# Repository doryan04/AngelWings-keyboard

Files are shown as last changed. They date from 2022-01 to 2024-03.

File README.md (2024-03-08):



# Angel Wings Keyboard (by [@ItzAdel](https://github.com/doryan04) and [@nm17](https://github.com/nm17))

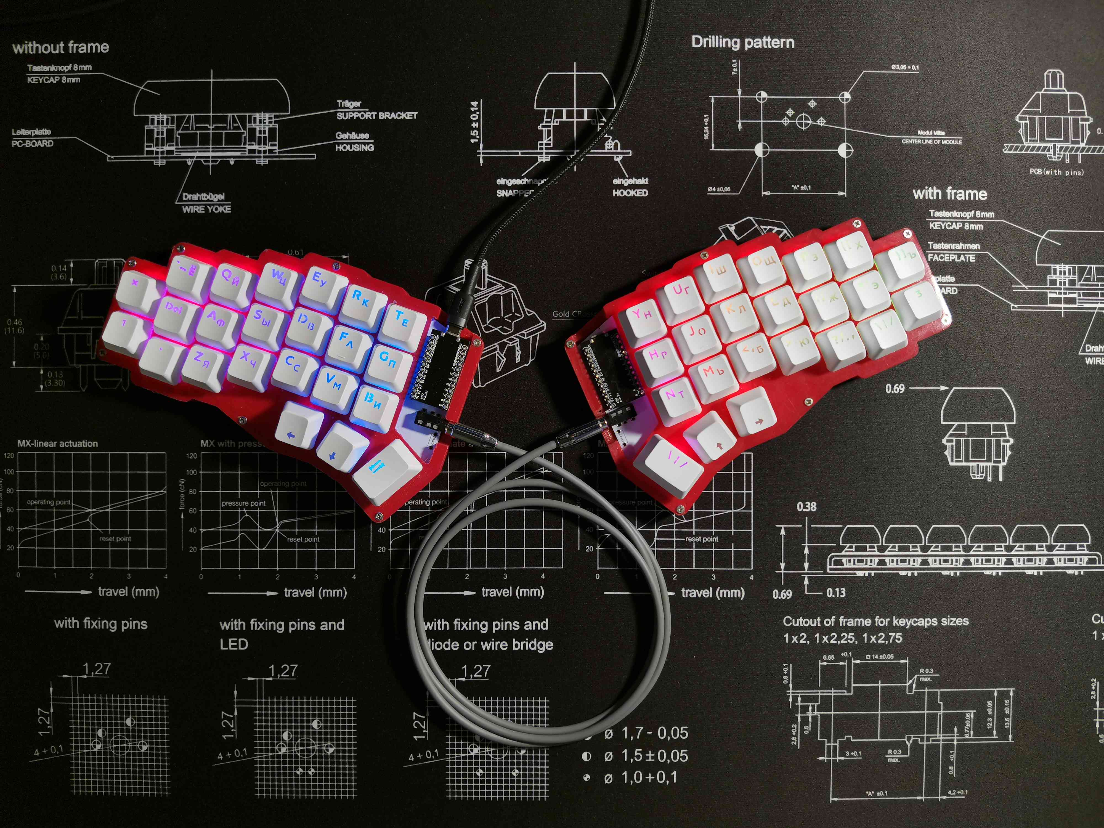
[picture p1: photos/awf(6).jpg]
Main Photo


# Keymap

The Lower, Raise and Adjust layers are provided to allow you to use full-size keys that are not on this keyboard.

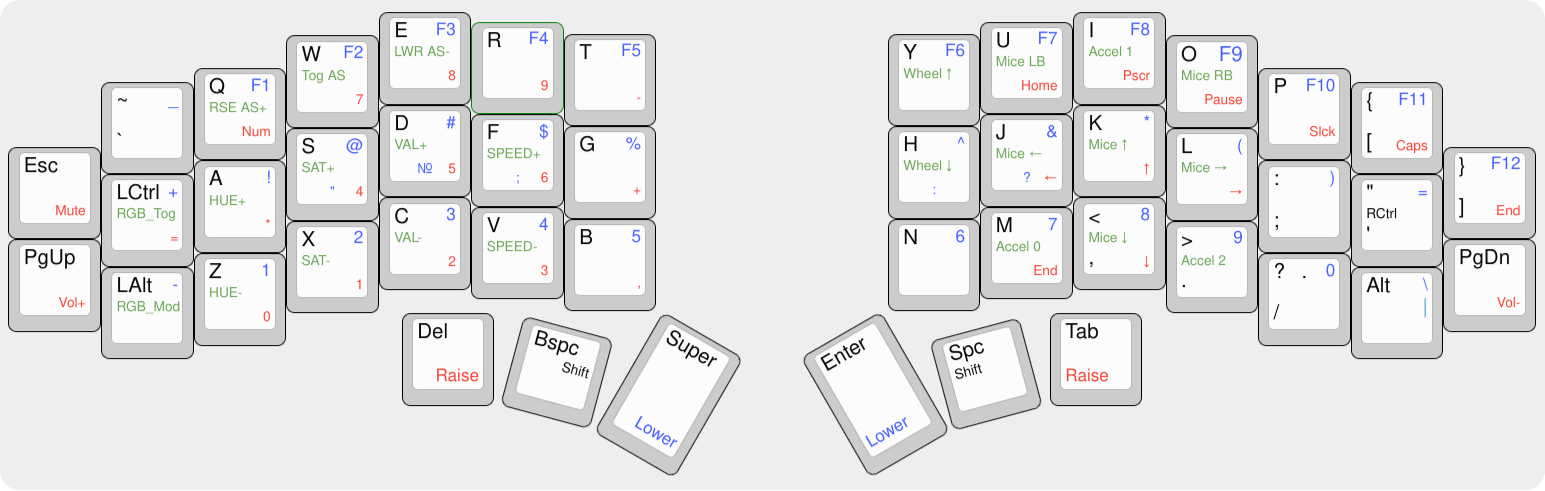
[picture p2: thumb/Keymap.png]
Keymap


To use one or the other layer, you need to press one of the following keys:
- Super/Enter for Lower.
- Tab/Delete for Raise
- To switch to the Adjust layer, press Enter + Tab / Super + Del

### Check [wiki](https://github.com/ItzAdel/AngelWings-keyboard/wiki/INFO) for more info

# Photos

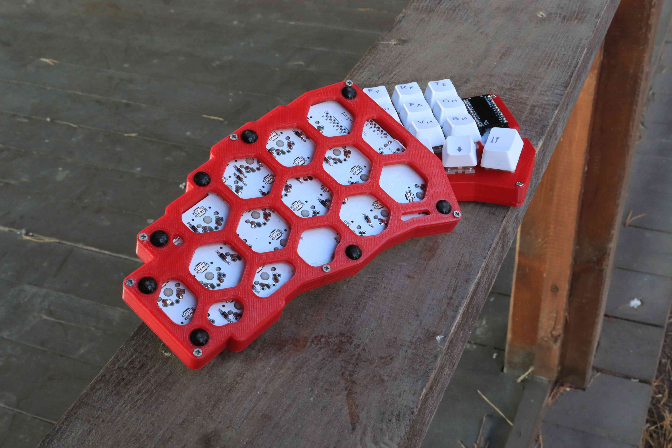
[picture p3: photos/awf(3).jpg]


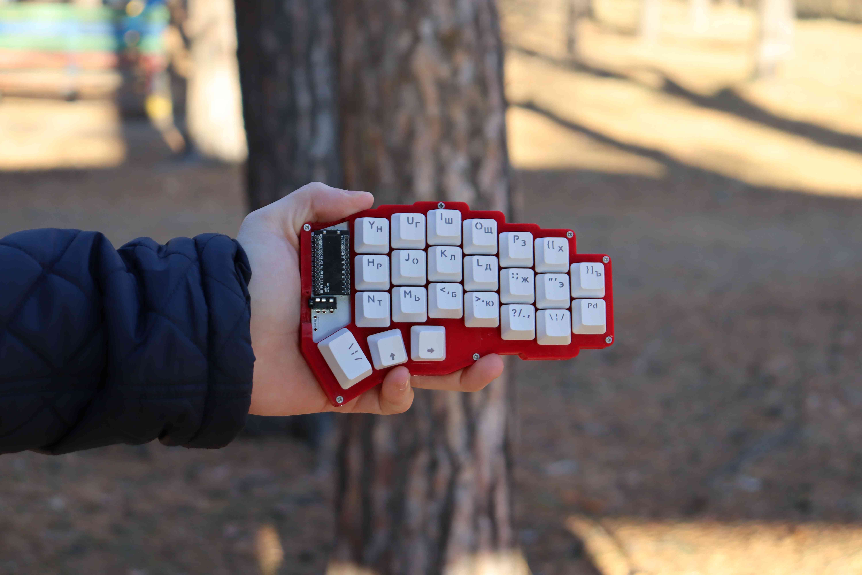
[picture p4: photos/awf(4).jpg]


# Nowadays, this repository is archived
## Check out updates AWF on [my gitea](https://gitea.doryan04.ru/doryan/AWF)

### Check out actual news on Telegram. https://t.me/doryanProjects

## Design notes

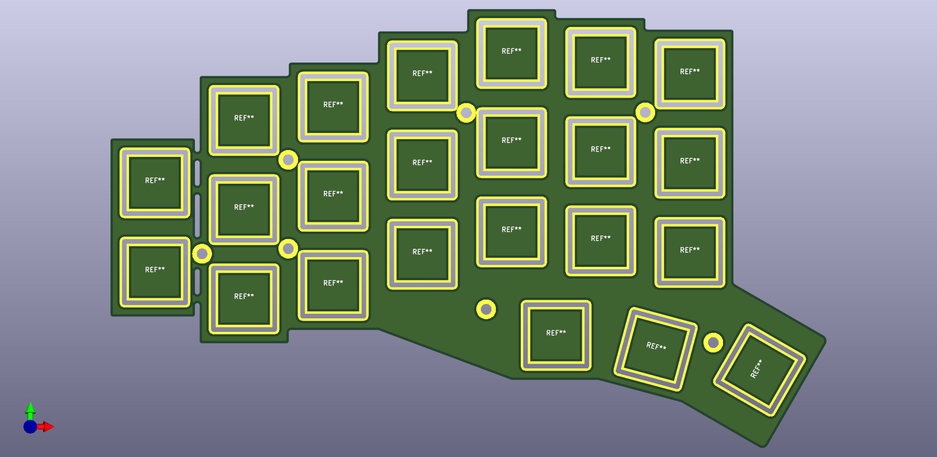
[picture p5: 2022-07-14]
photos/topplate.png

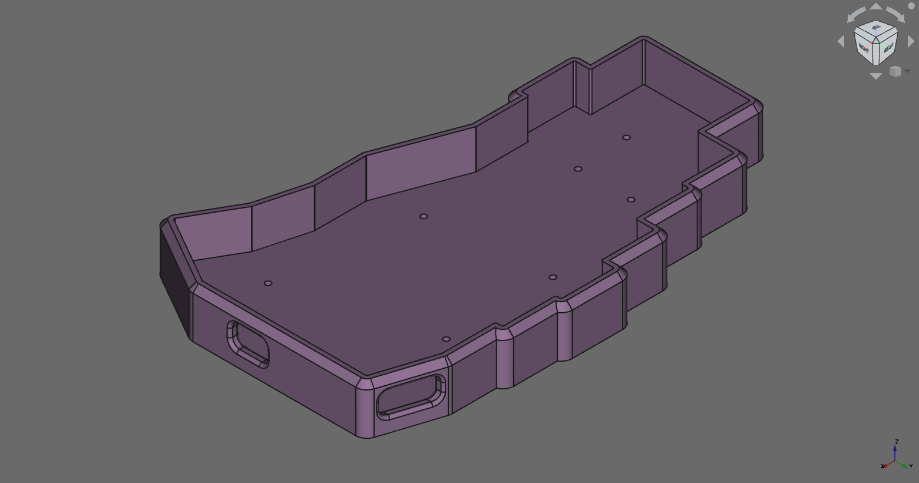
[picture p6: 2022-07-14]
cases/Pic/case3.png

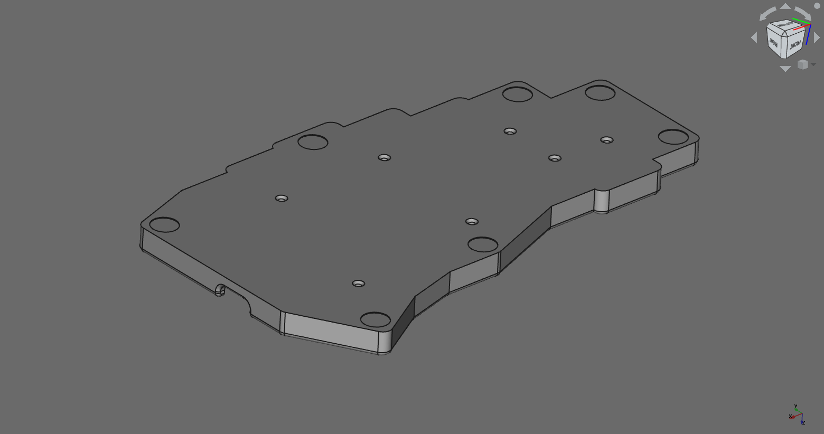
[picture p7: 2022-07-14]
cases/Pic/case1.png

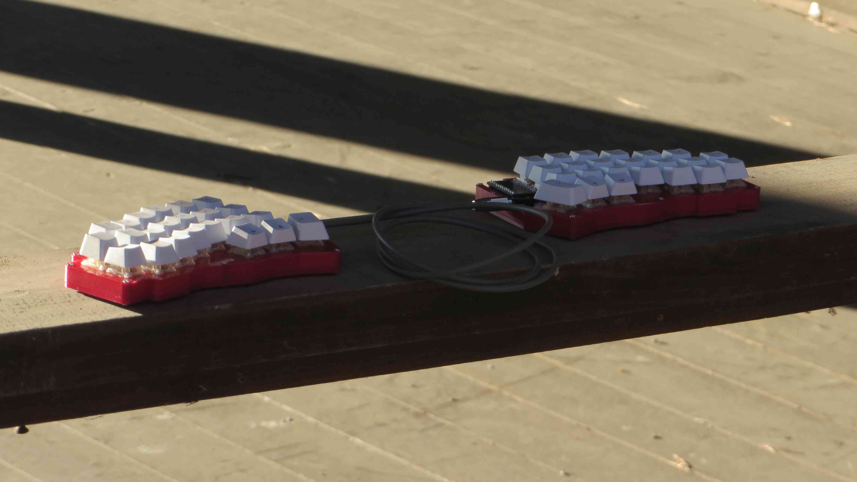
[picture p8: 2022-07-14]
photos/awf(2).jpg

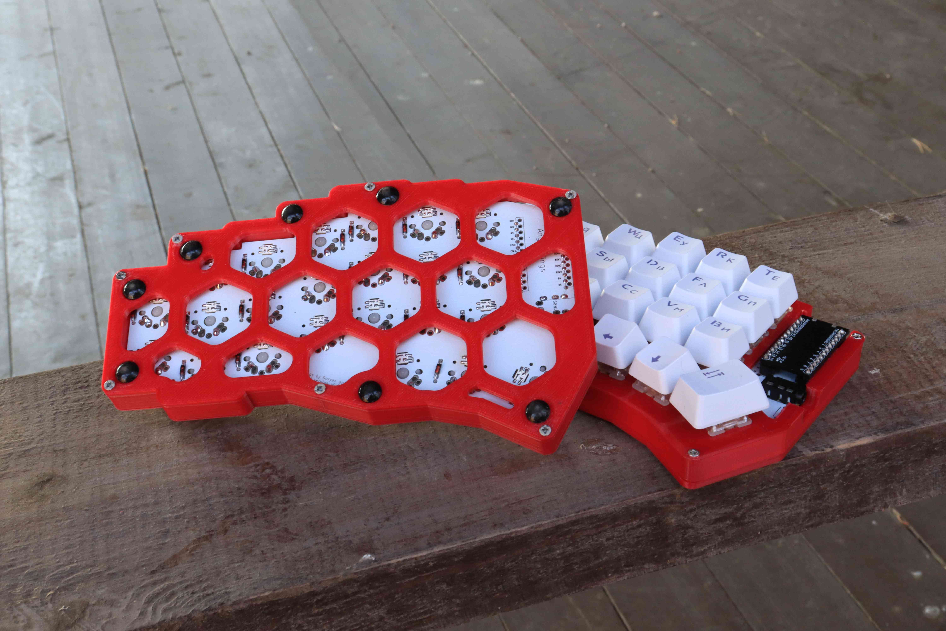
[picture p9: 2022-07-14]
photos/awf(5).jpg

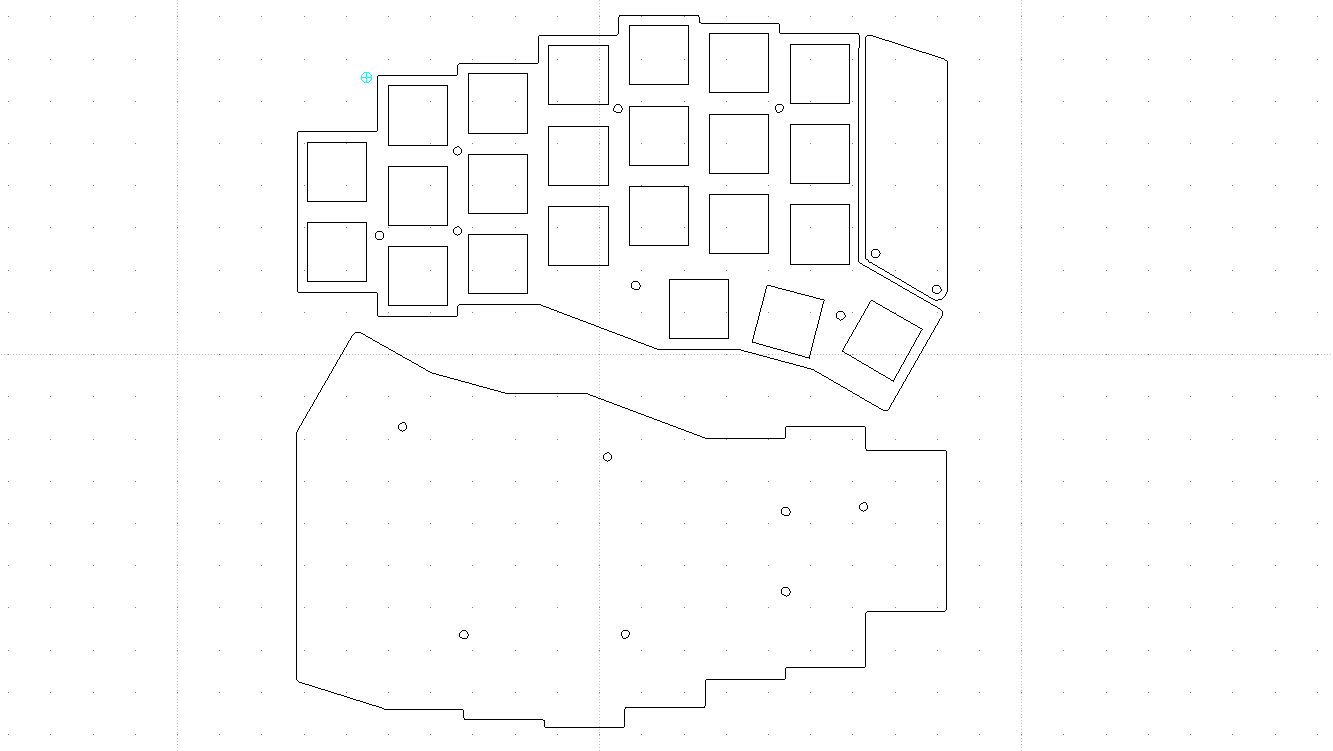
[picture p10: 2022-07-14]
cases/Pic/plates.png

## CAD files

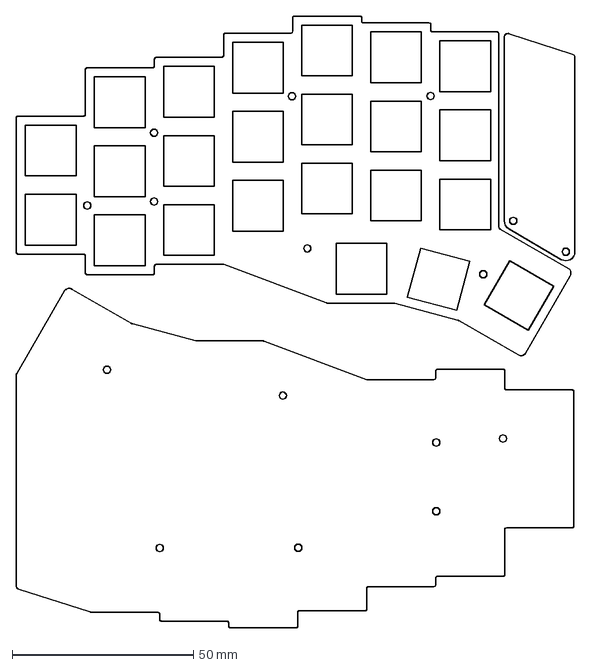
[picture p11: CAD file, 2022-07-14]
cases/Plates/plates.dxf
154.2 x 168.8 mm

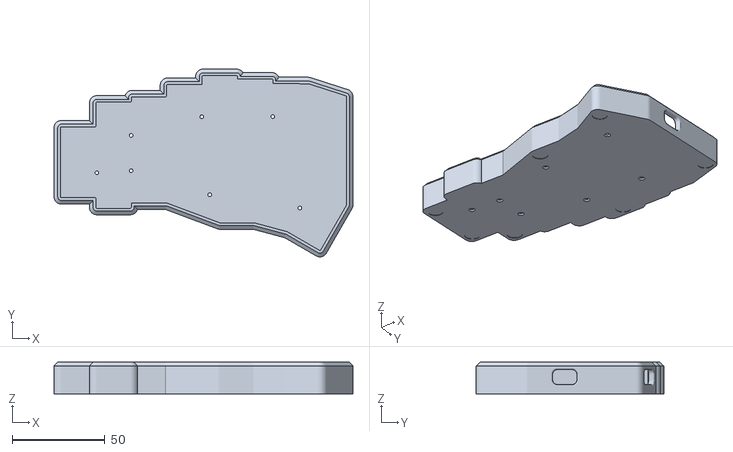
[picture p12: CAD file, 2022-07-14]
cases/STL cases/mxCase.stl
160.9 x 101.0 x 17.0

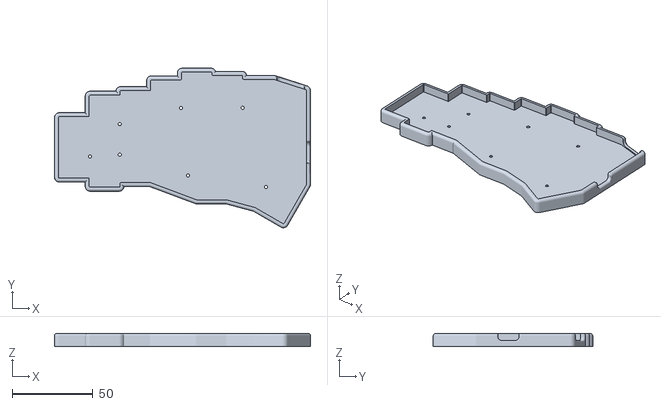
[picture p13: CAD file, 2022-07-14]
cases/STL cases/chocCase.stl
158.9 x 99.0 x 8.20

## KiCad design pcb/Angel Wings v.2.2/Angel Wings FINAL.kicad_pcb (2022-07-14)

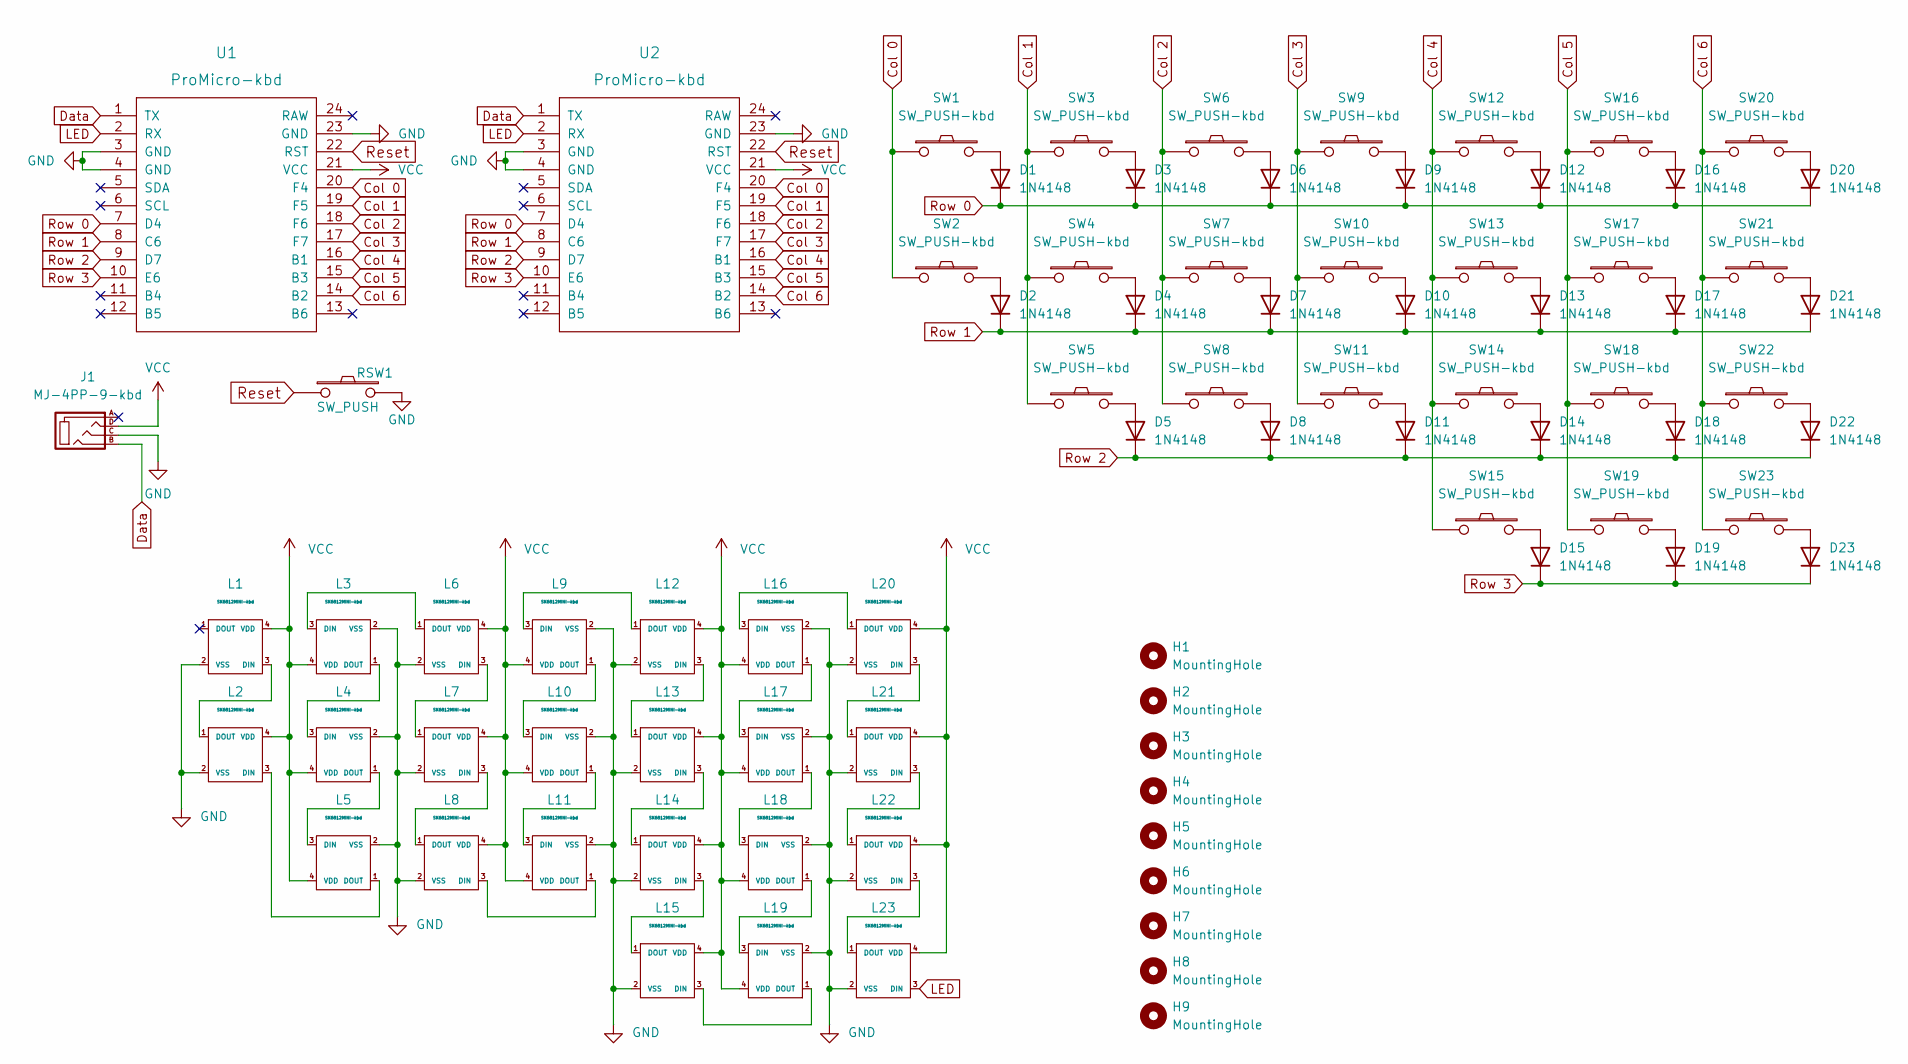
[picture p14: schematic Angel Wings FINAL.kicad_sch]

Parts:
D1, D2, D3, D4, D5, D6, D7, D8, D9, D10, D11, D12, D13, D14, D15, D16, D17, D18, D19, D20, D21, D22, D23: 1N4148; D3_TH_SMD
H1, H2: MountingHole; LEGO_HOLE
H3, H4, H5, H6, H7, H8, H9: MountingHole; M2_Hole_TH_Outside
J1: MJ-4PP-9-kbd; MJ-4PP-9
L1, L2, L3, L4, L5, L6, L7, L8, L9, L10, L11, L12, L13, L14, L15, L16, L17, L18, L19, L20, L21, L22, L23: SK6812MINI-kbd; SK6812MINI_rev
RSW1: SW_PUSH; ResetSW
SW1, SW2, SW3, SW4, SW5, SW6, SW7, SW8, SW9, SW10, SW11, SW12, SW13, SW14, SW15, SW16, SW17, SW18, SW19, SW20, SW21, SW22, SW23: SW_PUSH-kbd; MX_ALPS_PG1350_noLed
U1: ProMicro-kbd; ProMicro_Flipped_v2_A
U2: ProMicro-kbd; ProMicro_Flipped_v2_B

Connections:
Col 0: SW1.1, SW2.1, U1.20 (F4), U2.20 (F4)
Col 1: SW3.1, SW4.1, SW5.1, U1.19 (F5), U2.19 (F5)
Col 2: SW6.1, SW7.1, SW8.1, U1.18 (F6), U2.18 (F6)
Col 3: SW9.1, SW10.1, SW11.1, U1.17 (F7), U2.17 (F7)
Col 4: SW12.1, SW13.1, SW14.1, SW15.1, U1.16 (B1), U2.16 (B1)
Col 5: SW16.1, SW17.1, SW18.1, SW19.1, U1.15 (B3), U2.15 (B3)
Col 6: SW20.1, SW21.1, SW22.1, SW23.1, U1.14 (B2), U2.14 (B2)
Data: J1.B, U1.1 (TX), U2.1 (TX)
GND: J1.C, L1.2 (VSS), L2.2 (VSS), L3.2 (VSS), L4.2 (VSS), L5.2 (VSS), L6.2 (VSS), L7.2 (VSS), L8.2 (VSS), L9.2 (VSS), L10.2 (VSS), L11.2 (VSS), L12.2 (VSS), L13.2 (VSS), L14.2 (VSS), L15.2 (VSS), L16.2 (VSS), L17.2 (VSS), L18.2 (VSS), L19.2 (VSS), L20.2 (VSS), L21.2 (VSS), L22.2 (VSS), L23.2 (VSS), RSW1.2, U1.3 (GND), U1.4 (GND), U1.23 (GND), U2.3 (GND), U2.4 (GND), U2.23 (GND)
LED: L23.3 (DIN), U1.2 (RX), U2.2 (RX)
unnamed: D1.2 (A), SW1.2
unnamed: D2.2 (A), SW2.2
unnamed: D3.2 (A), SW3.2
unnamed: D4.2 (A), SW4.2
unnamed: D5.2 (A), SW5.2
unnamed: D6.2 (A), SW6.2
unnamed: D7.2 (A), SW7.2
unnamed: D8.2 (A), SW8.2
unnamed: D9.2 (A), SW9.2
unnamed: D10.2 (A), SW10.2
unnamed: D11.2 (A), SW11.2
unnamed: D12.2 (A), SW12.2
unnamed: D13.2 (A), SW13.2
unnamed: D14.2 (A), SW14.2
unnamed: D15.2 (A), SW15.2
unnamed: D16.2 (A), SW16.2
unnamed: D17.2 (A), SW17.2
unnamed: D18.2 (A), SW18.2
unnamed: D19.2 (A), SW19.2
unnamed: D20.2 (A), SW20.2
unnamed: D21.2 (A), SW21.2
unnamed: D22.2 (A), SW22.2
unnamed: D23.2 (A), SW23.2
unnamed: L1.3 (DIN), L2.1 (DOUT)
unnamed: L2.3 (DIN), L5.1 (DOUT)
unnamed: L3.1 (DOUT), L4.3 (DIN)
unnamed: L3.3 (DIN), L6.1 (DOUT)
unnamed: L4.1 (DOUT), L5.3 (DIN)
unnamed: L6.3 (DIN), L7.1 (DOUT)
unnamed: L7.3 (DIN), L8.1 (DOUT)
unnamed: L10.1 (DOUT), L11.3 (DIN)
unnamed: L9.1 (DOUT), L10.3 (DIN)
unnamed: L8.3 (DIN), L11.1 (DOUT)
unnamed: L9.3 (DIN), L12.1 (DOUT)
unnamed: L12.3 (DIN), L13.1 (DOUT)
unnamed: L13.3 (DIN), L14.1 (DOUT)
unnamed: L14.3 (DIN), L15.1 (DOUT)
unnamed: L15.3 (DIN), L19.1 (DOUT)
unnamed: L16.1 (DOUT), L17.3 (DIN)
unnamed: L16.3 (DIN), L20.1 (DOUT)
unnamed: L17.1 (DOUT), L18.3 (DIN)
unnamed: L18.1 (DOUT), L19.3 (DIN)
unnamed: L20.3 (DIN), L21.1 (DOUT)
unnamed: L21.3 (DIN), L22.1 (DOUT)
unnamed: L22.3 (DIN), L23.1 (DOUT)
Reset: RSW1.1, U1.22 (RST), U2.22 (RST)
Row 0: D1.1 (K), D3.1 (K), D6.1 (K), D9.1 (K), D12.1 (K), D16.1 (K), D20.1 (K), U1.7 (D4), U2.7 (D4)
Row 1: D2.1 (K), D4.1 (K), D7.1 (K), D10.1 (K), D13.1 (K), D17.1 (K), D21.1 (K), U1.8 (C6), U2.8 (C6)
Row 2: D5.1 (K), D8.1 (K), D11.1 (K), D14.1 (K), D18.1 (K), D22.1 (K), U1.9 (D7), U2.9 (D7)
Row 3: D15.1 (K), D19.1 (K), D23.1 (K), U1.10 (E6), U2.10 (E6)
VCC: J1.D, L1.4 (VDD), L2.4 (VDD), L3.4 (VDD), L4.4 (VDD), L5.4 (VDD), L6.4 (VDD), L7.4 (VDD), L8.4 (VDD), L9.4 (VDD), L10.4 (VDD), L11.4 (VDD), L12.4 (VDD), L13.4 (VDD), L14.4 (VDD), L15.4 (VDD), L16.4 (VDD), L17.4 (VDD), L18.4 (VDD), L19.4 (VDD), L20.4 (VDD), L21.4 (VDD), L22.4 (VDD), L23.4 (VDD), U1.21 (VCC), U2.21 (VCC)

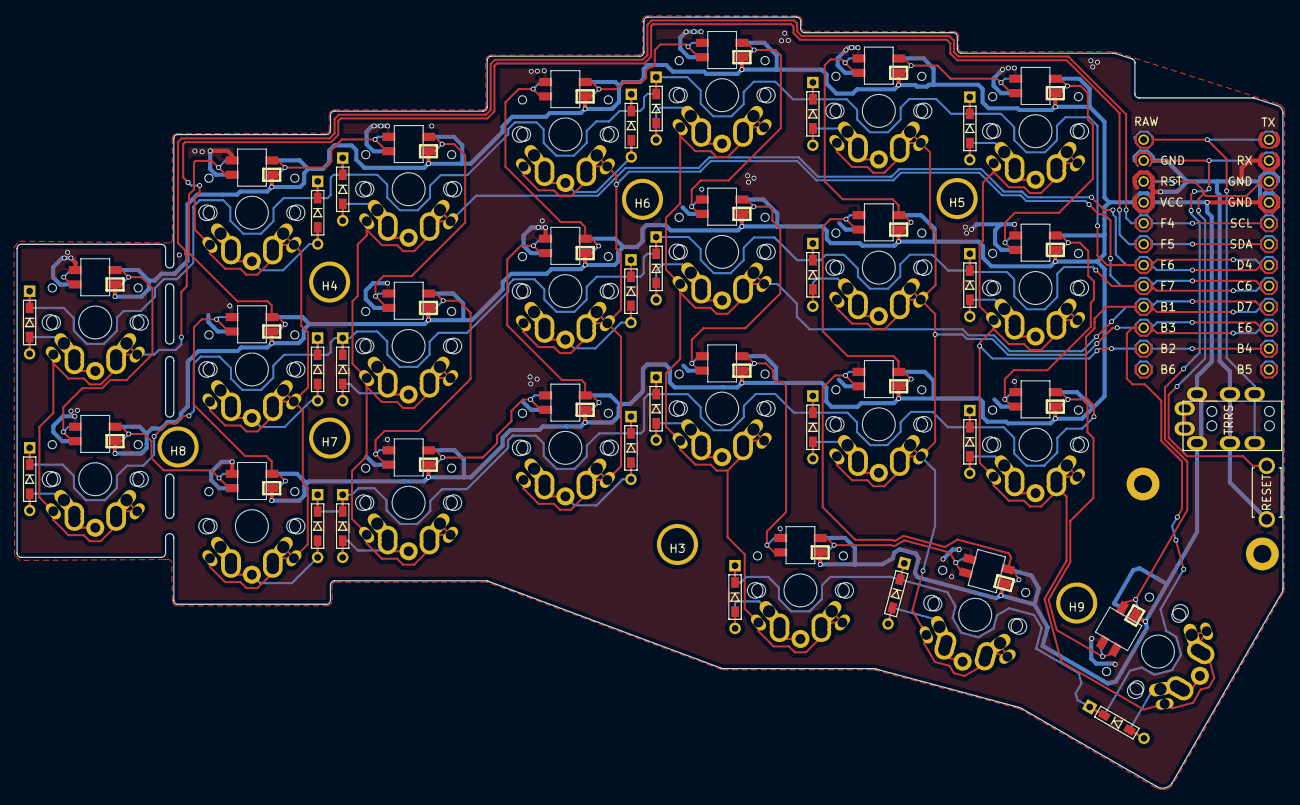
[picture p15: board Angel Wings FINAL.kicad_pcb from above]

Board: 2 copper layers, 153.9 x 93.7 mm, 82 parts (1 on the bottom side), 61 nets.

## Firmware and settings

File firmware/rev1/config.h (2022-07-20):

#pragma once

#define USE_SERIAL
#define SOFT_SERIAL_PIN D3
#define RGB_DI_PIN D2

#ifdef RGB_MATRIX_ENABLE
#    define RGBLED_NUM       46
#    define DRIVER_LED_TOTAL RGBLED_NUM
#    define RGB_MATRIX_SPLIT \
        { 23, 23 }

#   define RGB_DISABLE_AFTER_TIMEOUT 0
#   define RGB_DISABLE_WHEN_USB_SUSPENDED
#   define RGB_MATRIX_FRAMEBUFFER_EFFECTS
#    define RGB_MATRIX_MAXIMUM_BRIGHTNESS 130
#    define RGB_MATRIX_HUE_STEP 8
#    define RGB_MATRIX_SAT_STEP 8
#    define RGB_MATRIX_VAL_STEP 8
#    define RGB_MATRIX_SPD_STEP 10
#    define ENABLE_RGB_MATRIX_ALPHAS_MODS
#    define ENABLE_RGB_MATRIX_GRADIENT_UP_DOWN
#    define ENABLE_RGB_MATRIX_GRADIENT_LEFT_RIGHT
#    define ENABLE_RGB_MATRIX_BREATHING
#    define ENABLE_RGB_MATRIX_BAND_SAT
#    define ENABLE_RGB_MATRIX_BAND_VAL
#    define ENABLE_RGB_MATRIX_BAND_PINWHEEL_SAT
#    define ENABLE_RGB_MATRIX_BAND_PINWHEEL_VAL
#    define ENABLE_RGB_MATRIX_BAND_SPIRAL_SAT
#    define ENABLE_RGB_MATRIX_BAND_SPIRAL_VAL
#    define ENABLE_RGB_MATRIX_CYCLE_ALL
#    define ENABLE_RGB_MATRIX_CYCLE_LEFT_RIGHT
#    define ENABLE_RGB_MATRIX_CYCLE_UP_DOWN
#    define ENABLE_RGB_MATRIX_RAINBOW_MOVING_CHEVRON
#    define ENABLE_RGB_MATRIX_CYCLE_OUT_IN
#    define ENABLE_RGB_MATRIX_CYCLE_OUT_IN_DUAL
#    define ENABLE_RGB_MATRIX_CYCLE_PINWHEEL
#    define ENABLE_RGB_MATRIX_CYCLE_SPIRAL
#    define ENABLE_RGB_MATRIX_DUAL_BEACON
#    define ENABLE_RGB_MATRIX_RAINBOW_BEACON
#    define ENABLE_RGB_MATRIX_RAINBOW_PINWHEELS
#    define ENABLE_RGB_MATRIX_RAINDROPS
#    define ENABLE_RGB_MATRIX_JELLYBEAN_RAINDROPS
#    define ENABLE_RGB_MATRIX_HUE_BREATHING
#    define ENABLE_RGB_MATRIX_HUE_PENDULUM
#    define ENABLE_RGB_MATRIX_HUE_WAVE
#    define ENABLE_RGB_MATRIX_PIXEL_RAIN
#    define ENABLE_RGB_MATRIX_PIXEL_FLOW
#    define ENABLE_RGB_MATRIX_PIXEL_FRACTAL
// enabled only if RGB_MATRIX_FRAMEBUFFER_EFFECTS is defined
#    define ENABLE_RGB_MATRIX_TYPING_HEATMAP
#    define ENABLE_RGB_MATRIX_DIGITAL_RAIN
#endif

#define DIODE_DIRECTION COL2ROW

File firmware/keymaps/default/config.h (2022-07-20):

#pragma once

#ifdef RGBLIGHT_ENABLE
#    undef RGBLED_NUM
#    define RGBLIGHT_ANIMATIONS
#    define RGBLED_NUM 46
#    undef RGBLED_SPLIT
#    define RGBLED_SPLIT \
        { 23, 23 }
#    define RGBLIGHT_LIMIT_VAL 130
#    define RGBLIGHT_HUE_STEP  10
#    define RGBLIGHT_SAT_STEP  17
#    define RGBLIGHT_VAL_STEP  17
#endif

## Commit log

2022-01-01 KiCad files with plates
    [bottom plate.kicad_pcb, bottom plate.kicad_sch, top plate.kicad_pcb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]
2022-01-01 KiCad files with pcb
    [Angel Wings FINAL.kicad_pcb, Angel Wings FINAL.kicad_sch, angel wings.FCStd]
2022-01-01 Gerbers for plates and pcb
    [Angel Wings FINAL-B_Cu.gbl, Angel Wings FINAL-B_Mask.gbs, Angel Wings FINAL-B_Silkscreen.gbo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]
2022-01-07 Fix bugs
    [Angel Wings FINAL.kicad_pcb]
2022-01-07 Fixed info.json and fixed bugs in files for firmware
    [config.h]
2022-01-21 Gerbers PCB, Top plate & Bottom plate
    [Angel Wings FINAL-B_Cu.gbl, Angel Wings FINAL-B_Mask.gbs, Angel Wings FINAL-B_Silkscreen.gbo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]
2022-01-21 Angel Wings pcb version 1.1
    [Angel Wings FINAL.kicad_pcb, Angel Wings FINAL.kicad_sch]
2022-01-21 Angel Wings pcb version 2.0
    [Angel Wings FINAL.kicad_pcb, Angel Wings FINAL.kicad_sch]
2022-01-21 deleted old file
    [Angel Wings FINAL.kicad_pcb]
2022-01-24 fix AWF v.2.1
    [Angel Wings FINAL.kicad_pcb, Angel Wings FINAL.kicad_sch]
2022-01-24 Gerbers update
2022-07-14 New gerber AWF 2.2 pcb
2022-07-14 Add AWF 2.2
    [Angel Wings FINAL.kicad_pcb, Angel Wings FINAL.kicad_sch]
2022-07-14 Add STL cases for MX and Choc + add DXF plate
    [chocCase.stl, mxCase.stl, plates.dxf]
2022-07-14 Deleted old PCB ver. 2
    [Angel Wings FINAL.kicad_pcb, Angel Wings FINAL.kicad_sch]
2022-07-14 New PCB photo
2022-07-14 Deleted old version PCB
